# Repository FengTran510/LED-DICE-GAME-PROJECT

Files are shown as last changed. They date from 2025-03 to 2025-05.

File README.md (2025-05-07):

# Feature: LED DICE GAME PROJECT (Group Project)

## Contributor: 
| Name | ID |
|---|---|
| Tran Duc Phong | 2251042 |
| Nguyen Huu Dai Nhan | 2251039 |
| Nguyen Vo Thien An | 2151172 |

## 1. Introduction: 
You are invited to reference - test on the main branch, which is the result of Group Project about LED DICE GAME-project for playing board game. We haven't completed testing this feature yet but we expect it would work. If you do test it, please let me know and I'll adjust and merge it to master.

## 2. Tool used

### 2.1. MicrochipStudio 

### 2.2. Altium

## 3. Design and Architecture

## 4. Sample of Design
### 4.1. General block diagram of project
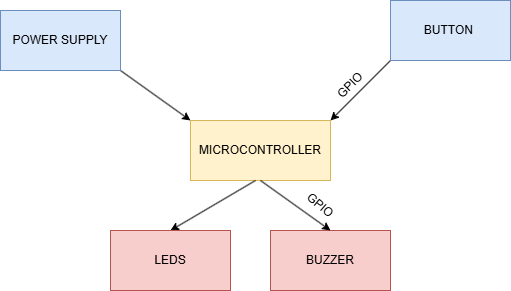
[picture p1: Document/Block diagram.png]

- March 22nd, 2025 - Note: This is just a referencing version for system operation (not verified) -> if there is any errors, please don't hesitate to contact us (Contributor).

### 4.2. PCB Layout
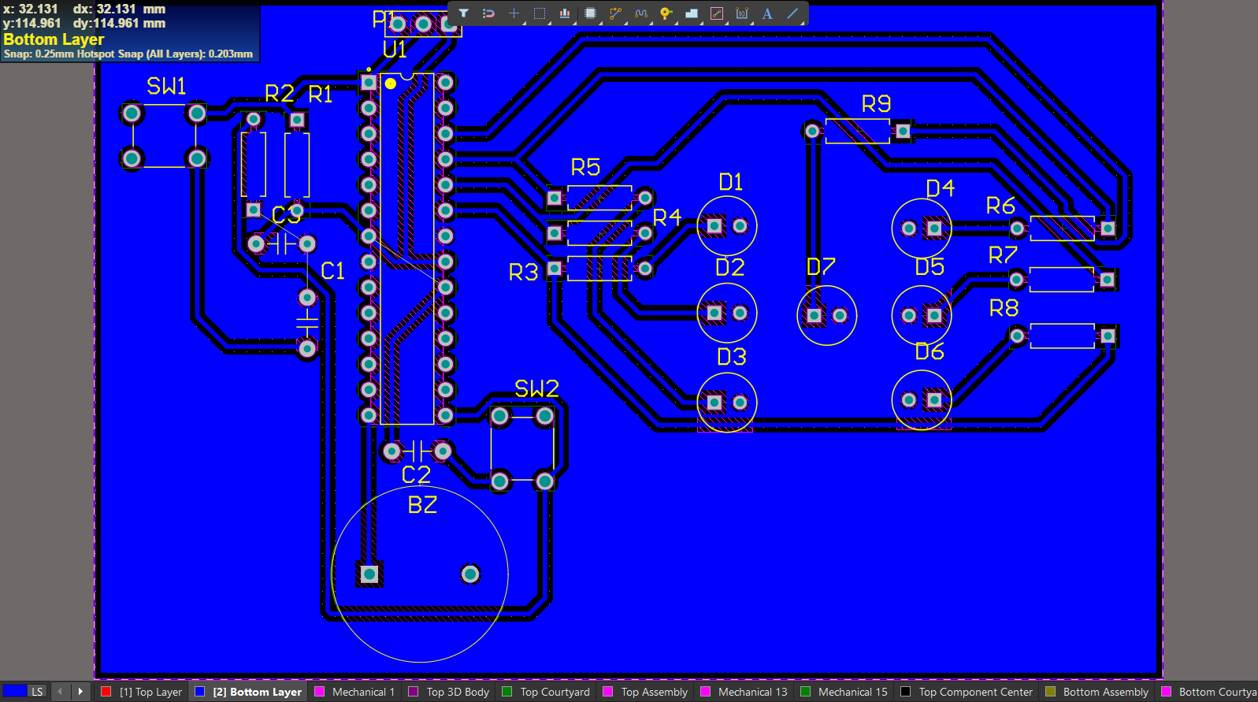
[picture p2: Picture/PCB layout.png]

- March 22nd, 2025 - Note: This is the first version of board development without testing -> refer only.

### 4.3. PCB Design (3D)
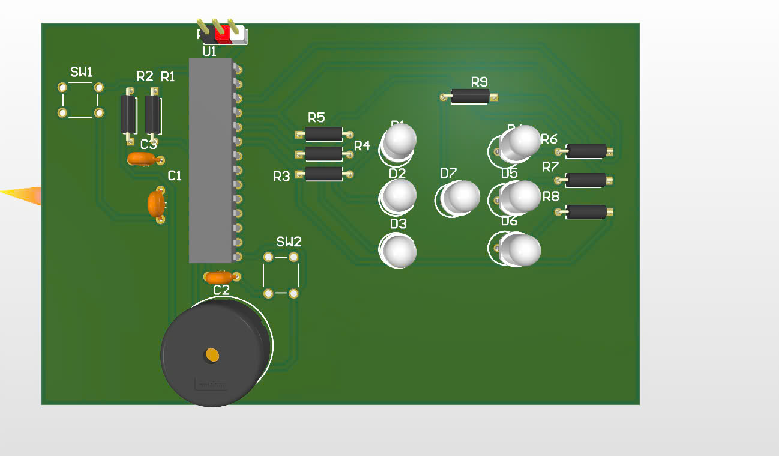
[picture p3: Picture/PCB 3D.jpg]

- March 26th, 2025 - Note: This is the first version of board development without testing -> refer only.

### 4.4. Schematic Design of system
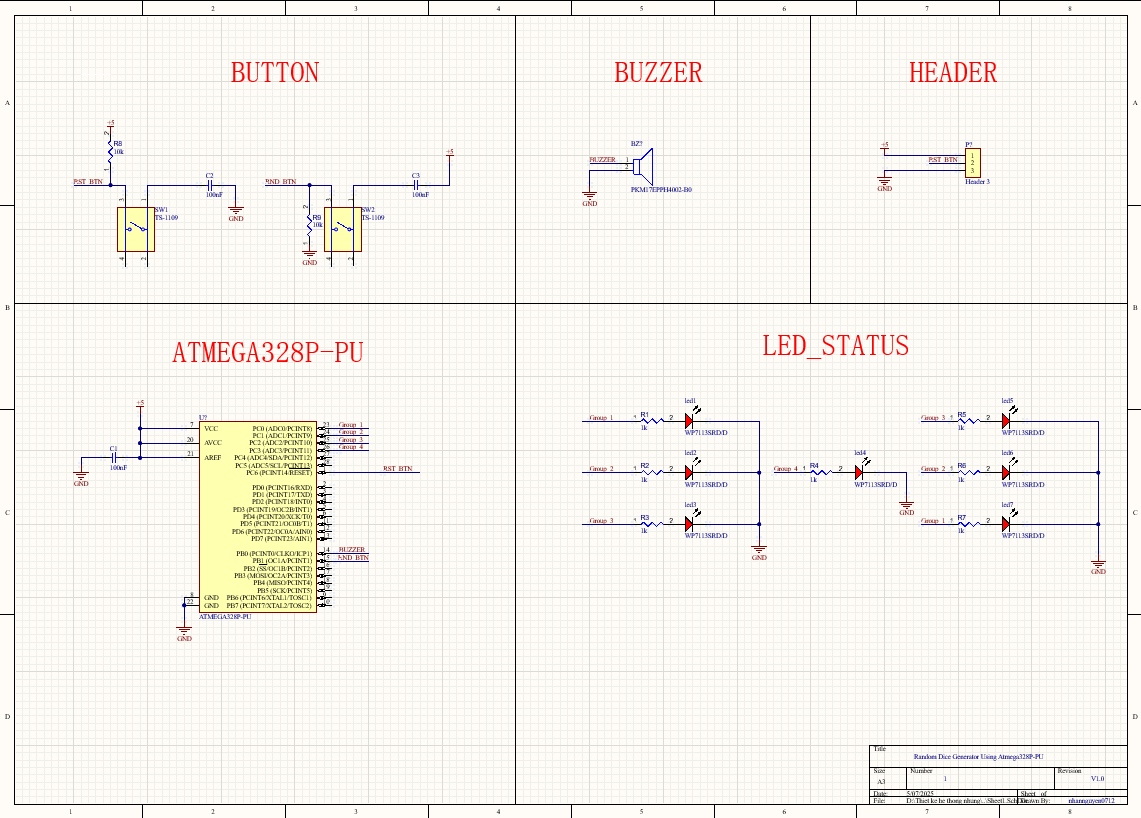
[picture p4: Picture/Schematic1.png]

- March 22nd, 2025 - Note: This is the first version of board development without testing -> refer only.

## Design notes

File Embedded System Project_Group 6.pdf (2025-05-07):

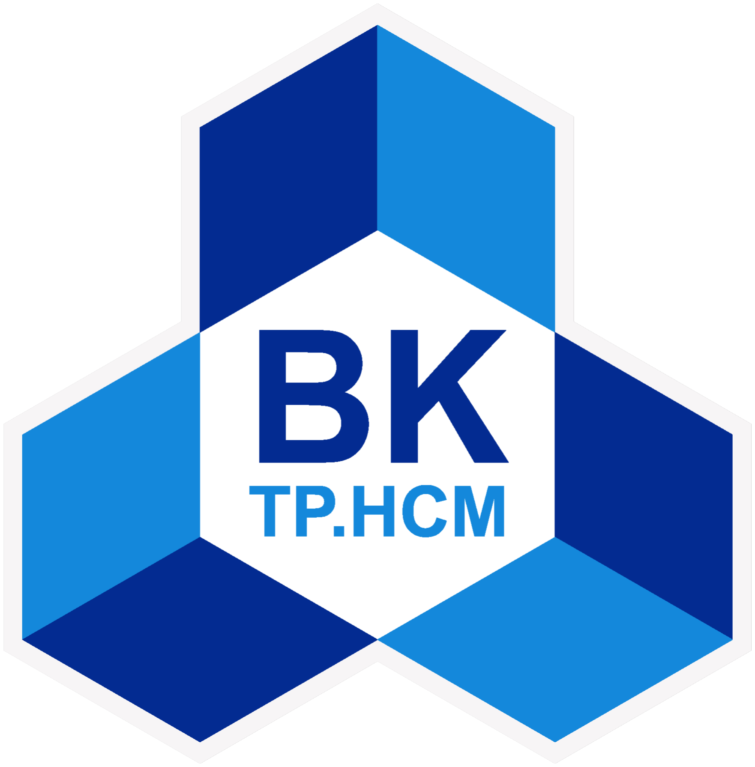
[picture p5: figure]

## Ho Chi Minh City University of Technology

### Faculty of Electrical & Electronics Engineering

A Member of Vietnam National University

# Design of Schematic and PCB Layout for an LED Dice Game using ATmega328P

### A Course Project in Embedded Systems

### Members: Nguyen Huu Dai Nhan - 2251039 Tran Duc Phong - 2251042 Nguyen Vo Thien An - 2151172

### Supervisor: Bui Quoc Bao

### Date: May 05, 2025

### Course Code: [EE3427]

Ho Chi Minh City University of Technology Faculty of Electrical and Electronics Engineering

## Mục lục

1 Introduction | 3
2 Project Overview | 3
3 System Design | 4
4 Schematic Design | 5
5 PCB Layout Design | 6
6 Software Implementation | 7
7 Results and Analysis | 7
8 Conclusion | 8
9 References | 8
Embedded System - Semester 2024-2025 | Page 1/12

Faculty of Electrical and Electronics Engineering

## Abstract

This project presents the design and implementation of an LED dice game using the ATmega328P microcontroller. The system displays random numbers (1–6) through four LED groups, triggered by a push-button input with interrupt-driven control, and provides audio feedback via a buzzer. The schematic and PCB layout were designed using Altium, with firmware programmed via a USBasp programmer in the Arduino IDE. Key features include a 600ms rolling animation, random number generation seeded by analog noise, a 50ms button debounce, and a funny beep pattern (30/50/70ms). The prototype was tested for functionality, achieving reliable operation with clear visual and audio feedback. Power consumption is approximately 50–100mA at 5V. The project demonstrates skills in embedded systems, AVR programming, and PCB design, serving as an educational tool for microcontroller-based applications.

Faculty of Electrical and Electronics Engineering

## 1 Introduction

### 1.1 Background

Electronic dice are interactive embedded systems that combine microcontroller programming with circuit design, offering a practical platform for learning. This project develops an LED dice game using the ATmega328P, integrating hardware and software to simulate a traditional dice with modern electronics.

### 1.2 Motivation

The project serves as an educational tool for embedded systems and engages students and hobbyists with an interactive electronic device.

## 2 Project Overview

### 2.1 Project Goals

- Implement a functional LED dice game with ATmega328P.
- Ensure reliable random number generation and user interaction.
- Design a compact PCB with USBasp programming support.

### 2.2 Tools Used

- Altium for schematic and PCB design.
- Proteus for simulation and verification
- Arduino IDE for firmware development.
- USBasp programmer for ATmega328P programming.

### 2.3 List of Components

- ATmega328P microcontroller.
- Four LED groups (GROUP_1, GROUP_2, GROUP_3, LED_4).
- Reset button (PC6, INT1).
- Active buzzer (PB0).
- 6-pin ISP header for USBasp.
- 1KΩ resistors, 100µF capacitors, 5V power supply.

Faculty of Electrical and Electronics Engineering

## 3 System Design

### 3.1 Functional Requirements

The LED dice game must:
- Display random numbers (1–6) using four LED groups.
- Trigger rolls via a reset button with interrupt on PC6.
- Provide audio feedback (200ms beep, funny beep pattern).
- Implement a 600ms rolling animation with 200ms blinks.

Performance goals include <1s response time, reliable random numbers, and 50ms button debounce.

### 3.2 Block Diagram


Figure 1: Block Diagram of LED Dice Game.

The system includes the ATmega328P, four LED groups (PC0-PC3), a reset button (PC6), a buzzer (PB0), a 6-pin ISP header, and a 5V power supply.

### 3.3 Component Selection

- ATmega328P: 8-bit AVR, 32 KB flash, 23 I/O pins, Arduino-compatible.
- LEDs: 3mm/5mm, 20mA, red/green.
- Reset Button: Momentary, PC6, external pull-up.
- Buzzer: Active, PB0.
- USBasp ISP Header: 6-pin for MOSI, MISO, SCK, RESET, VCC, GND.
- Others: 1kΩ resistors, 0.1µF capacitors, 5V power.

Faculty of Electrical and Electronics Engineering

Component | Quantity | Part Number | Cost (vnd)
ATmega328P LED (Blue) Button Buzzer 6-pin ISP Header 1kΩ Resistor 0.1µF Capacitor | 1 7 1 1 1 4 1 | ATMEGA328P-PU WP7113SRD/D TS-119 PKM17EPPH4002-B0 HS0787 | 75.000 5.000 20.000 7.000 69.000 2.000 2.000

Table 1: Bill of Materials (BOM).

## 4 Schematic Design


Figure 2: Schematic Diagram of LED Dice Game.

The schematic includes:

- ATmega328P: PC0-PC3 (pins 23–26) for LEDs, PC6 (pin 1) for button, PB0 (pin
14) for buzzer, SPI pins for ISP.
- LEDs: Four groups with 1kΩ resistors, active-high.
- Push Button: PC6, external pull-up, FALLING interrupt.

Faculty of Electrical and Electronics Engineering

- Buzzer: PB0, active buzzer.
- ISP Header: 6-pin for USBasp (MOSI, MISO, SCK, RESET, VCC, GND).
- Power: 5V with 0.1µF decoupling capacitor.

### 4.1 Design Considerations

- LED current limited to <20mA per pin.
- Interrupt-driven button for responsiveness.
- Accessible ISP header for USBasp.
- Decoupling capacitor for power stability.

## 5 PCB Layout Design

The PCB was designed by importing the schematic into ALtium, defining a 10cm × 7cm board, placing components, routing traces, and generating Gerber files.

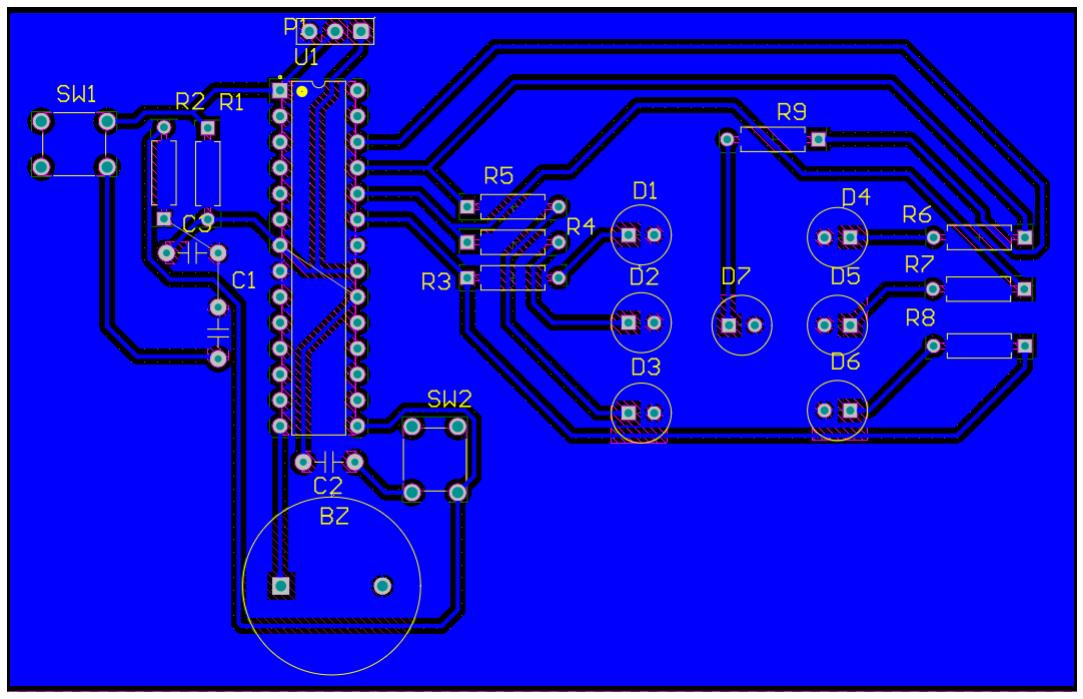
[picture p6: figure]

Figure 3: PCB Layout (Top and Bottom Layers).

### 5.1 Design Considerations

- Component Placement: ATmega328P central, LEDs in dice pattern, button accessible, buzzer near edge, ISP header near board edge.

Faculty of Electrical and Electronics Engineering

- Routing: 10–12 mil signal traces, 20–30 mil power traces, 20 mil clearance, short LED traces, dedicated SPI for ISP.
- Power and Ground: Bottom-layer ground plane, 5V rail with decoupling.
- Manufacturability: 6 mil minimum trace width, aligned ISP header.

Tools: Altium. Challenges like ISP routing congestion were resolved by adjusting header placement.

## 6 Software Implementation

The firmware controls the ATmega328P for LED patterns, button interrupts, and buzzer, programmed via USBasp in Arduino IDE.

### 6.1 Key Algorithms

- Random Number: randomSeed(analogRead(A0)) seeds with noise, random(1, 7) for 1–6.
- LED Control: DICE_FACES array defines patterns, set_face() maps to PB0–PB3.
- Button: Interrupt on PD3, 50ms debounce in buttonISR.
- Buzzer: beep(200) for 200ms, funny_beep_pattern() for 30/50/70ms beeps.
- Rolling Effect: 600ms, 200ms blinks.

### 6.2 Programming Environment

Developed in Arduino IDE, with USBasp configured as the programmer. The USBasp connects to the 6-pin ISP header (MOSI, MISO, SCK, RESET, VCC, GND). The ATmega328P uses a 16 MHz clock.

## 7 Results and Analysis

### 7.1 Functional Accuracy

The LED dice game operates reliably, displaying correct LED patterns, responding to button inputs, and producing audio feedback.

### 7.2 Performance

- Accurate LED patterns for all faces.
- Responsive button with 50ms debounce.
- Even random number distribution.
- Clear buzzer audio at 1m.

Faculty of Electrical and Electronics Engineering

### 7.3 Goals vs. Achievements

Achieved functional dice, USBasp integration, and audio feedback. ISR debounce is non-ideal for production.

### 7.4 Limitations

Single button, active buzzer tone restrictions, no power-saving mode.

### 7.5 Improvements

- Move debounce to loop().
- Support passive buzzer.
- Add sleep mode.

## 8 Conclusion

### 8.1 Summary

Successfully designed an LED dice game with ATmega328P, USBasp programming, and a compact PCB.

### 8.2 Future Work

- Add OLED for score tracking.
- Optimize PCB size.
- Use ATtiny for cost reduction.

## 9 References

- ATmega328P Datasheet, Microchip Technology.
- IPC-2221: Generic Standard on Printed Board Design.
- Arduino IDE Reference, https://www.arduino.cc/reference.
- USBasp Documentation, https://www.fischl.de/usbasp.
- Monk, S., “Programming Arduino: Getting Started with Sketches,” McGraw-Hill.

Faculty of Electrical and Electronics Engineering

### Source Code

Complete AVR code available in project repository.

1 #i n cl u d e <i o . h>
2 #i n cl u d e <d ela y . h>

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

6
7 | // Pin d e f i n i t i o n s f o r LEDs, button , and buzze r (ATmega328P r e g i s t e r s )
8 #d e f i n e GROUP_1_PIN 0 | // PC0 ( Arduino pin A0)
9 #d e f i n e GROUP_2_PIN 1 | // PC1 ( Arduino pin A1)
10 #d e f i n e GROUP_3_PIN 2 | // PC2 ( Arduino pin A2)
11 #d e f i n e LED_4_PIN | 3 | // PC3 ( Arduino pin A3)
12 #d e f i n e RND_BTN | 1 | // PB1 ( with e x t e r n a l p ull −up)
13 | // Al t e r n a ti v e : Use PC6 ( r e q u i r e s RSTDISBL f u s e )
14 | // #d e f i n e RND_BTN | 6 | // PC6 ( with e x t e r n a l p ull −up , r e q u i r e s RSTDISBL
| f u s e )
15 #d e f i n e BUZZER | 0 | // PB0 ( Arduino pin 8 )

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

22
23 | // Dice f a c e s ( b i t p a t t e r n s f o r LEDs, a d j u s t e d f o r c o r r e c t pin mapping )
24 | co n s t un signed cha r DICE_FACES[ 6 ] = {
25 | (1 << LED_4_PIN) , | | // Face 1 : LED_4 (PC3)
26 | (1 << GROUP_1_PIN) , | | // Face 2 : GROUP_1 (PC0)
27 | (1 << GROUP_1_PIN) | (1 << LED_4_PIN) , // Face 3 : GROUP_1 (PC0) + LED_4
| (PC3)
28 | (1 << GROUP_1_PIN) | (1 << GROUP_3_PIN) , // Face 4 : GROUP_1 (PC0) +
| GROUP_3 (PC2)
29 | (1 << GROUP_1_PIN) | (1 << GROUP_3_PIN) | (1 << LED_4_PIN) , // Face 5 :
GROUP_1 (PC0) + GROUP_3 (PC2) + LED_4 (PC3)
30 | (1 << GROUP_1_PIN) | (1 << GROUP_2_PIN) | (1 << GROUP_3_PIN) // Face 6 :
GROUP_1 (PC0) + GROUP_2 (PC1) + GROUP_3 (PC2)

31 } ;

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

Faculty of Electrical and Electronics Engineering

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

53
54 | void i n i t _ i o ( void ) {
55 | // Se t PC0, PC1, PC2, PC3 a s ou tpu t s f o r LEDs
56 | DDRC. 0 = 1 ;
57 | DDRC. 1 = 1 ;
58 | DDRC. 2 = 1 ;
59 | DDRC. 3 = 1 ;

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

64
65 | // Al t e r n a ti v e : Use PC6 ( r e q u i r e s RSTDISBL f u s e )
66 | // DDRC. 6 = 0 ;
67 | // PORTC. 6 = 0 ;

68
69 | // Se t PB0 a s output f o r buzze r
70 | DDRB. 0 = 1 ;

71
72 | // I n i t i a l i z e ou tpu t s to OFF
73 | PORTC. 0 = 0 ;
74 | PORTC. 1 = 0 ;
75 | PORTC. 2 = 0 ;
76 | PORTC. 3 = 0 ;
77 | PORTB. 0 = 0 ;
78 | }

79
80 | void cl e a r _l e d s ( void ) {
81 | PORTC. 0 = 0 ;
82 | PORTC. 1 = 0 ;
83 | PORTC. 2 = 0 ;
84 | PORTC. 3 = 0 ;
85 | }

86
87 | void s e t_ fa c e ( un signed cha r face_id x ) {
88 | un signed cha r pa t t e r n = DICE_FACES[ face_id x ] ;
89 | PORTC. 0 = ( pa t t e r n & (1 << GROUP_1_PIN) ) ? 1 : 0 ;
90 | PORTC. 1 = ( pa t t e r n & (1 << GROUP_2_PIN) ) ? 1 : 0 ;
91 | PORTC. 2 = ( pa t t e r n & (1 << GROUP_3_PIN) ) ? 1 : 0 ;
92 | PORTC. 3 = ( pa t t e r n & (1 << LED_4_PIN) ) ? 1 : 0 ;
93 | }

94
95 | void funny_beep_pattern ( void ) {
96 | un signed cha r i ;
97 | f o r ( i = 0 ; i < 3 ; i++) {
98 | PORTB. 0 = 1 ; // Buzzer ON
99 | delay_ms (10 * (3 + i * 2 ) ) ; // 30 , 50 , 70 ms
100 | PORTB. 0 = 0 ; // Buzzer OFF

Faculty of Electrical and Electronics Engineering

101 | delay_ms (5 0 ) ; // 50ms pause
102 | }
103 | }

104
105 | void short_beep ( void ) {
106 | PORTB. 0 = 1 ; // Buzzer ON
107 | delay_ms (100 ) ; // Sho r t 100ms beep
108 | PORTB. 0 = 0 ; // Buzzer OFF
109 | }

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

131
132 | void main ( void ) {
133 | i n i t _ i o ( ) ;

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

147
148 | // Wait f o r button p r e s s (PB1 go e s LOW due to p ull −up)
149 | // Al t e r n a ti v e : Use PINC. 6 i f u si ng PC6 with RSTDISBL f u s e
150 | i f ( ! PINB. 1 ) {
151 | // Debounce : Wait and co n fi rm button s t a t e
152 | delay_ms (DEBOUNCE_TIME) ;
153 | i f ( ! PINB. 1 ) {

Faculty of Electrical and Electronics Engineering

154 | // Sho r t beep to co n fi rm button p r e s s
155 | short_beep ( ) ;

156
157 | // Accumulate co u n t e r i n c r em e n t s du ring button p r e s s to
| vary the s e e d
158 | w hil e ( ! PINB. 1 ) {
159 | co u n t e r++;
160 | i f ( co u n t e r > 65535 ) co u n t e r = 0 ;
161 | s e e d_mo di fi e r = ( s e e d_mo di fi e r + co u n t e r ) ^ ( co u n t e r >>
| 2 ) ; // Fu r the r vary the s e e d
162 | delay_ms (1 0 ) ;
163 | }
164 | r oll _ s e e d = ( co u n t e r ^ s e e d_mo di fi e r ) + ( s e e d_mo di fi e r >>
| 1 ) ; // Combine f o r b e t t e r v a r i a t i o n
165 | r o l l i n g _ e f f e c t ( r oll _ s e e d ) ;
166 | f i n a l _ f a c e = get_random_face ( r oll _ s e e d + ( s e e d_mo di fi e r <<
| 2 ) ) ;
167 | show_face ( f i n a l _ f a c e ) ;
168 | }
169 | }
170 | }
171 | }
Listing 1: AVR Code for LED Dice Game

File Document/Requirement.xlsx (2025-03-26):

Project: | LED DICE GAME
1 | The dice game should be compact and portable
1.1 | All things should be done just in a PCB for durability and reliability
1.2 | The total weight of the device shall not exceed 200 grams
2 | The dice should can do these functions below
2.1 | The device shall simulate a dice roll using two LEDs
2.2 | The LEDs shall display numbers from 1 to 6 in a random manner
2.3 | The user shall be able to initiate a dice roll by pressing a button
2.4 | The LEDs shall remain the result until pressing the button
3 | Interface requirement
3.1 | The button shall be easy to press
3.2 | The LED brightness shall be sufficient to be clearly visible in normal lighting conditions
3.3 | The system shall provide a visual indication when a roll is in progress (e.g., blinking effect)
4 | Hardware requirement
4.1 | The device shall use a microcontroller to control LED behavior
4.2 | The power supply use battery or low-power source (5V-1A)
4.3 | The button shall be debounced
4.4 | The LEDs used shall be energy-efficient and long-lasting
5 | Software requirement
5.1 | The system shall use a random number generator algorithm to simulate the dice roll
5.2 | The firmware shall be optimized for low power consumption

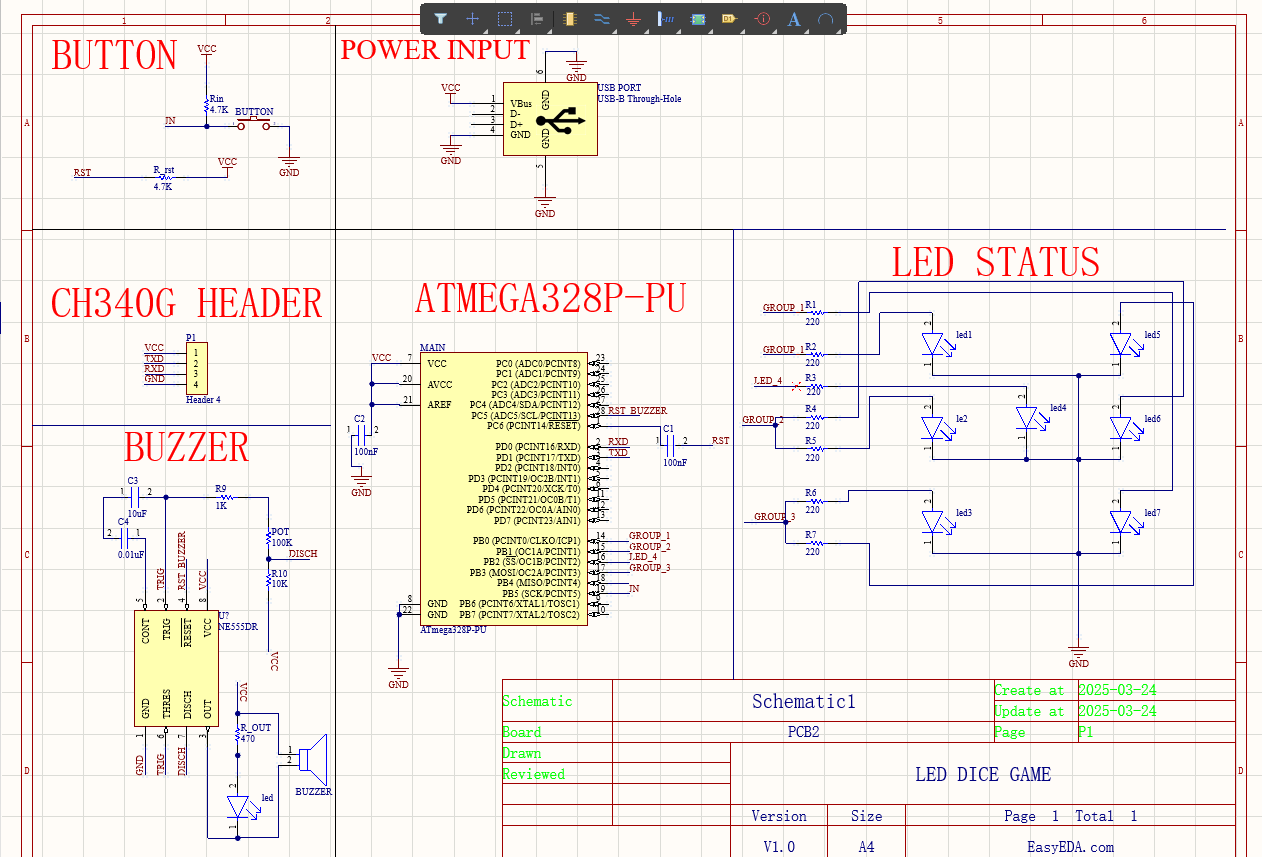
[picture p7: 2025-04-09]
Picture/Schematic.png

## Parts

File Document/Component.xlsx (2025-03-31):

No. | Component | Quanlity | Explaination
1 | ATmega328P-PU | 1 | The microprocessor to apply the code which simulate the dice
2 | Led Red 5mm | 7 | Use to show the result of dice
3 | 220 ohms and 10K ohms resistor | 7 | Help the current not overloaded
4 | Push button | 2 | One for turn on/off, one for random the dice
5 | Header | 1 | Apply code to the schematic
6 | Power input | 1 | Power supply
Note: All of this will connect in PCB

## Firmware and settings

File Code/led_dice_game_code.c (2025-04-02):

#define F_CPU 16000000UL

#include <avr/io.h>
#include <util/delay.h>
#include <stdlib.h>

// LED pins (PORTB)
#define LED1_7   PB0
#define LED2_6   PB1
#define LED4     PB2
#define LED3_5   PB3

// Buzzer control pin (PC5)
#define BUZZER   PC5

// Button input pin
#define BUTTON   PB5 // Assuming button is connected to PB5

#define DISPLAY_TIME 2000

// Die face patterns: [PB3, PB2, PB1, PB0]
const uint8_t die_patterns[6][4] = {
	{0, 0, 0, 1}, // 1
	{0, 0, 1, 0}, // 2
	{0, 0, 0, 1}, // 3
	{1, 1, 1, 0}, // 4
	{1, 0, 1, 1}, // 5
	{1, 1, 1, 0}  // 6
};

void init_io() {
	// Set PB0–PB3 as output (LEDs)
	DDRB |= (1 << PB0) | (1 << PB1) | (1 << PB2) | (1 << PB3);

	// Set PC5 as output for buzzer control
	DDRC |= (1 << BUZZER);
	PORTC &= ~(1 << BUZZER); // Ensure buzzer is OFF by default

	// Set PB5 as input for button
	DDRB &= ~(1 << BUTTON);
	PORTB |= (1 << BUTTON); // Enable pull-up
}

uint8_t button_pressed() {
	if (!(PINB & (1 << BUTTON))) {
		_delay_ms(20); // debounce
		if (!(PINB & (1 << BUTTON))) {
			while (!(PINB & (1 << BUTTON))); // wait for release
			return 1;
		}
	}
	return 0;
}

void clear_leds() {
	PORTB &= ~((1 << PB0) | (1 << PB1) | (1 << PB2) | (1 << PB3));
}

void beep() {
	// Trigger the 555 timer to start buzzing by setting PC5 LOW
	PORTC &= ~(1 << BUZZER); // Set PC5 LOW to trigger 555 timer
	_delay_ms(300); // Buzz for 300ms
	PORTC |= (1 << BUZZER); // Set PC5 HIGH to stop the buzzer
	_delay_ms(100); // Pause between beeps
}

void show_roll(uint8_t roll) {
	clear_leds();

	// Get pattern for the rolled value
	uint8_t *p = (uint8_t *)die_patterns[roll - 1];
	if (p[0]) PORTB |= (1 << PB3);
	if (p[1]) PORTB |= (1 << PB2);
	if (p[2]) PORTB |= (1 << PB1);
	if (p[3]) PORTB |= (1 << PB0);

	_delay_ms(DISPLAY_TIME);
	clear_leds();
}

int main(void) {
	init_io();

	// Seed random with a fixed value (e.g., 1234)
	srand(1234);  // Using a constant seed (can be any number)

	while (1) {
		if (button_pressed()) {
			beep(); // Trigger the buzzer
			uint8_t roll = (rand() % 6) + 1;
			show_roll(roll);
		}
	}
}
